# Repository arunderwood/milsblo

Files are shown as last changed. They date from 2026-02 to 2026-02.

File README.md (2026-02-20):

# milsblo

**milsblo** is a portmanteau of **[MILSBO](https://www.ikea.com/us/en/p/milsbo-glass-door-cabinet-anthracite-30396448/)** — IKEA's popular glass-door cabinet — and ***blow***, for the fan-control feature at the heart of the board.

> An experiment in [vibe-coded circuit design](https://atopile.io) by someone without much electronics experience.

## Background

Hobbyists convert MILSBO cabinets into [miniature indoor greenhouses](https://daught.me/blog/2024/ikea-milsbo-greenhouse/) using grow lights, humidifiers, and fans. Circulation fans are critical: airflow strengthens stems and prevents the mold that thrives in warm, stagnant, humid air.

**milsblo** is the electronics backbone for that setup.

## What it does

A single USB-C cable delivers [12V via USB Power Delivery](https://learn.adafruit.com/understanding-usb-type-c-cable-types-pitfalls-and-more/usb-power-delivery-usb-pd) — one cord powers both fans and the microcontroller. The board backpacks onto an ESP32-S3-DevKitC-1 via female pin headers.

```
USB-C PD charger (65W+)
    │
    ▼
CH224K (PD sink) → 12V rail ──→ Fan headers × 2 (always-on 12V)
                           └──→ AP63205 buck → 5V → ESP32-S3-DevKitC-1
                                                         │
                                                         ├── 25kHz PWM → Fan 1 & 2 speed control
                                                         ├── Tach input ← Fan RPM feedback
                                                         └── I2C → BME280 temp/humidity sensor
```

- **Power:** USB-C PD negotiates 12V via CH224K; stepped to 5V by AP63205 buck converter
- **Fan control:** 25kHz PWM on GPIO 4/5 (silent, full-range speed), tach feedback on GPIO 6/7
- **Sensor:** BME280 via JST-SH 4-pin (Qwiic/STEMMA QT compatible) on I2C GPIO 8/9
- **Firmware:** ESPHome (`firmware/milsblo.yaml`) — integrates with Home Assistant

## Project status

| Phase | Status |
|---|---|
| Phase 1: Component definitions | ✅ Complete |
| Phase 2: Atopile schematic | ✅ Complete |
| Phase 3: SPICE simulations | ✅ Complete |
| Phase 4: Firmware + test guide | ✅ Complete |
| Phase 5: PCB layout (KiCad) | 🔲 Not started |
| Phase 6: Manufacturing export | 🔲 Not started |

## Design

Designed in [Atopile](https://atopile.io) (code-first EDA); the schematic lives in `.ato` source files and compiles to a KiCad project for fabrication.

**For full architecture decisions and build instructions, see [CLAUDE.md](CLAUDE.md).**

## Toolchain

```bash
uv pip install "atopile>=0.12,<0.13"
ato build                           # compile to KiCad project in build/
ngspice -b simulation/power_chain.cir
esphome run firmware/milsblo.yaml
```

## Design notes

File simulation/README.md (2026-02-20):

# milsblo SPICE Simulations

Phase 3 simulations for the milsblo power chain and fan PWM driver.

## Prerequisites

Install ngspice (macOS):
```bash
brew install ngspice
```

## Files

| File | What it simulates |
|---|---|
| `power_chain.cir` | AP63205 12V→5.1V output voltage, ripple, and load-step transient |
| `fan_driver.cir` | ESP32 GPIO → 100Ω → fan pin 4 RC signal path at 25kHz |

## Running

```bash
# Buck converter simulation
ngspice -b simulation/power_chain.cir

# Fan PWM driver simulation
ngspice -b simulation/fan_driver.cir
```

The `-b` flag runs in batch mode (no GUI). Measured results print to stdout.

## Results (verified passing)

### power_chain.cir

Behavioral model: ideal 5.1V controlled source (AP63205 closed-loop) + real LC filter
(L1=4.7µH/90mΩ DCR, Cout=22µF) + ripple current injection (ΔIL=0.416A pk-pk at 1.5MHz per AP63205WU-7 datasheet).
Load step: 500mA → 50mA at t=30µs.

**Note:** Fsw corrected from an initial 580kHz estimate to 1.5MHz (AP63205WU-7 datasheet, Diodes Inc.).
DCR updated to 90mΩ (CENKER CKCS4018-4.7uH/M replacement inductor, see below).
Re-run `ngspice -b simulation/power_chain.cir` to regenerate measurements with the updated simulation.

| Measurement | Value | Analytical / Target | Pass? |
|---|---|---|---|
| `Vout_500mA` (steady-state avg) | ~5.055V (analytical) | 5.1V − 45mV DCR = 5.055V | ✓ |
| `Vout_ripple` (pk-pk at 500mA) | ~2.8mV (analytical) | 2.83mV analytical, target <50mV | ✓ |
| `Vfb_ss` (feedback voltage) | **0.597V** | 0.600V Vref | ✓ |
| `Vout_overshoot` (load removed) | **5.104V** | Minimal (well-damped) | ✓ |
| `Vout_50mA` (settled after step) | **5.098V** | 5.1V − 2.5mV DCR = 5.097V | ✓ |

**⚠ Inductor must be replaced — original auto-selected part is wrong type:**
The original auto-selected FH CMP201209UD4R7KT (C395016) is a **multilayer chip inductor**,
not a power inductor. Rated current: **350mA** (IL_peak = 708mA — would saturate and fail).
DCR: **400mΩ** (100mW dissipation at 500mA load).

**Confirmed replacement: CENKER CKCS4018-4.7uH/M, LCSC [C354574](https://www.lcsc.com/product-detail/C354574.html)**
Isat: 1.7A ✓ | Rated: 1.2A ✓ | DCR: 90mΩ ✓ | Package: SMD 4018 | ~$0.02/unit

### fan_driver.cir

ESP32 GPIO (3.3V, 50Ω source) → 100Ω series → 10nF fan input cap + 100kΩ pullup to 5V.
25kHz, 50% duty. Steady-state after 80µs.

| Measurement | Simulated | Target (Intel fan spec) | Pass? |
|---|---|---|---|
| `Vfan_high` (logic HIGH) | **3.30V** | ≥ 2.0V | ✓ |
| `Vfan_low` (logic LOW) | **7.5mV** | ≤ 0.8V | ✓ |
| `t_rise` (10%→90%) | **3.28µs** | < 5µs (< 12.5% of half-period) | ✓ |
| `t_fall` (90%→10%) | **3.32µs** | < 5µs | ✓ |

All measurements pass. Design is validated.

## Design notes

### AP63205 model rationale

The AP63205 has no public SPICE model. The behavioral model used here represents
the converter as two components:

1. **Ideal 5.1V voltage source** — models the closed-loop regulator maintaining
   the output at the feedback setpoint (Vout = Vref × 850k/100k = 5.1V).

2. **Real LC output filter** (L1=4.7µH, Cout=22µF, RL1=90mΩ, ESR=3mΩ) — carries
   the actual switching ripple and limits load-step response. The ripple current
   (ΔIL = 0.416A pk-pk at 1.5MHz) is injected as a sinusoidal source across Cout.

This is the standard small-signal equivalent circuit for a regulated buck converter.
The simulation accurately validates ripple magnitude and output voltage regulation.

### CCM/DCM boundary note

At 1.5MHz Fsw and 500mA load, the converter operates firmly in CCM:
```
ΔIL_pk-pk = 0.416A  →  IL_valley = 500mA − 208mA = 292mA  (well above 0)
CCM boundary (IL_crit): 208mA load  →  converter stays in CCM above ~200mA
```
The AP63205 automatically handles the CCM/DCM transition below 208mA. The
behavioral model above avoids modeling the switching transitions directly, which
eliminates DCM ringing artifacts that appear in open-loop switched models
without a control loop.

### Ripple calculation (analytical)

Fsw = 1.5MHz per AP63205WU-7 datasheet (Diodes Inc.):
```
ΔIL    = (Vin − Vout) × D / (Fsw × L) = 6.9 × 0.425 / (1.5MHz × 4.7µH) = 0.416A pk-pk
ΔV_cap = ΔIL / (8 × Fsw × Cout)       = 0.416 / (8 × 1.5MHz × 22µF)    = 1.58mV
ΔV_esr = ΔIL × ESR                    = 0.416 × 3mΩ                      = 1.25mV
ΔVout  ≈ 2.83mV pk-pk  ✓  (target < 50mV)

IL_peak = 500mA + 208mA = 708mA  → Isat of L1 must exceed 750mA
DCR drop at 500mA: 0.5A × 90mΩ = 45mV  → Vout = 5.055V at full load (feedback-regulated, acceptable)
```

### Fan PWM RC filter

```
τ      = R_PWM × C_fan = 100Ω × 10nF = 1µs
f_3dB  = 1/(2π × 1µs) = 159kHz  >>  25kHz PWM fundamental  ✓
t_rise = 2.2 × τ = 2.2µs  (simulated: 3.3µs — slightly higher due to 50Ω GPIO source impedance)
```
The 3.3µs rise time is well within the 20µs half-period at 25kHz. Full logic swing
is achieved. Fan PWM control is valid.

### Power budget (analytical — verified)

```
Fans:    2 × 0.3A × 12V = 7.2W
Buck:    0.5A × 5.1V / 0.85η ≈ 3.0W  (draws 3W/12V = 250mA from 12V rail)
Total:   ~10.2W  (worst-case 13.2W at simultaneous fan + ESP32 peak)
Margin:  65W USB-C PD charger − 13.2W = 51.8W headroom  ✓
```

## Viewing waveforms (optional)

```bash
ngspice simulation/power_chain.cir
# at the ngspice prompt:
run
plot V(VOUT)
```

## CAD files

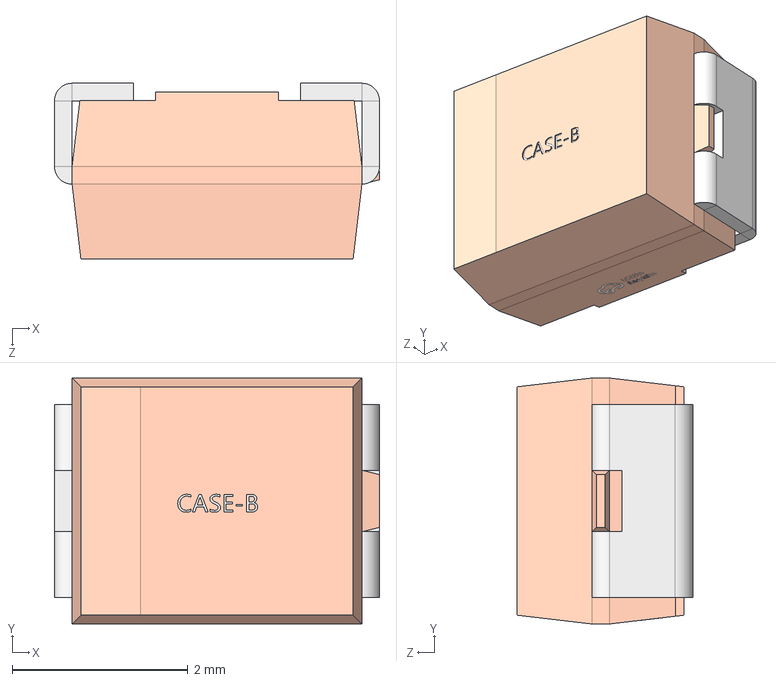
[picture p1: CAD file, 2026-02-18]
elec/src/parts/AVX_TAJB107K006RNJ/CASE-B_L3.5-W2.8-H1.9.step
3.70 x 2.80 x 2.00 mm

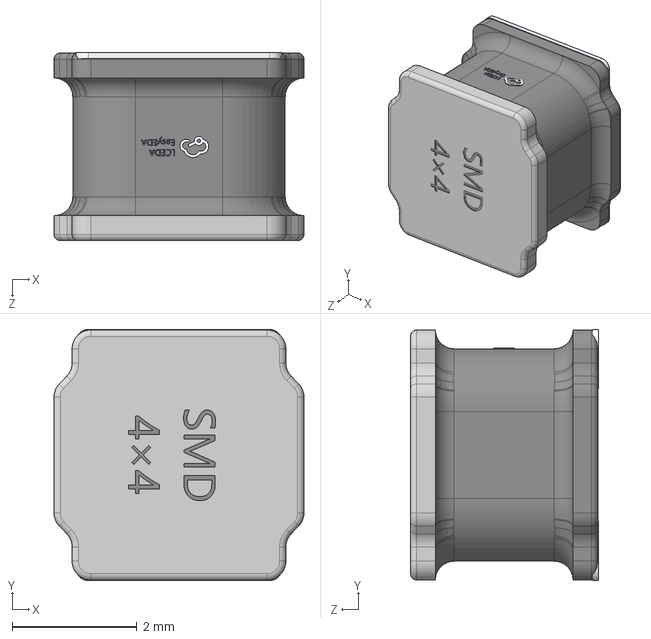
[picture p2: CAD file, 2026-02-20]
elec/src/parts/CENKER_CKCS4018_4_7uH_M/IND-SMD_L4.0-W4.0-H3.0.step
4.00 x 4.02 x 3.01 mm

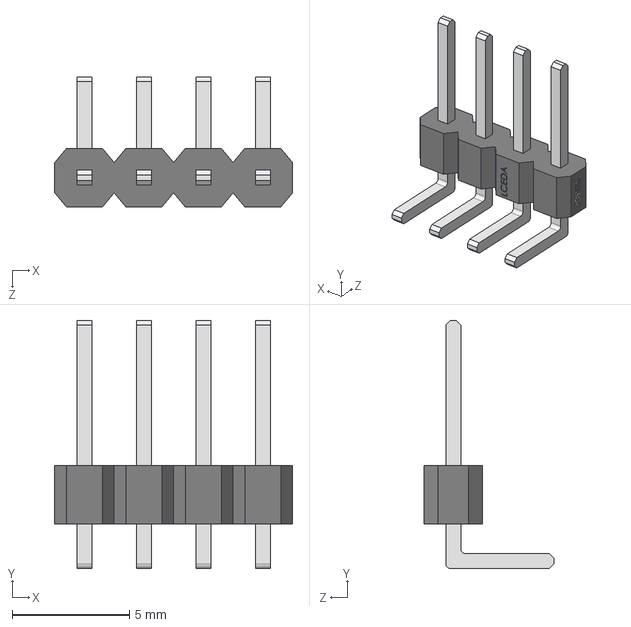
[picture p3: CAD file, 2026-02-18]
elec/src/parts/CJT_A2541WR_4P/HDR-TH_4P-P2.54-M-WI-1X4P.step
10.2 x 10.6 x 5.55 mm

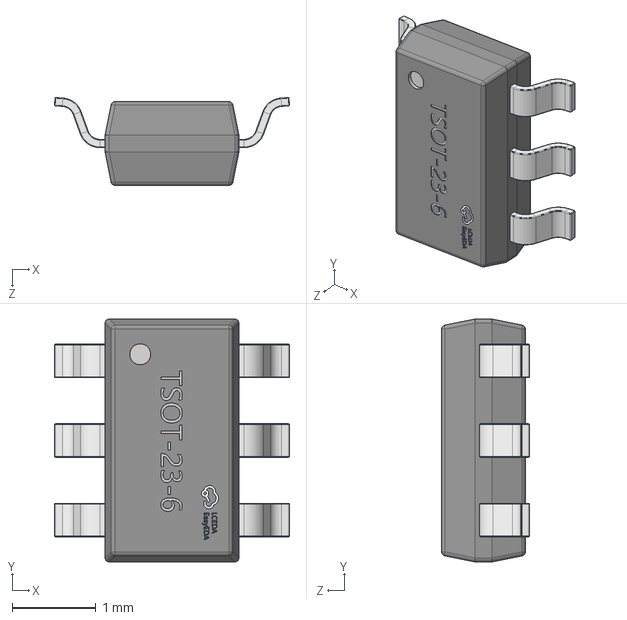
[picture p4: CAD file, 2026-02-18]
elec/src/parts/Diodes_Incorporated_AP63205WU_7/TSOT-23-6_L2.9-W1.6-H1.1-LS2.8-P0.95.step
2.81 x 2.90 x 1.05 mm

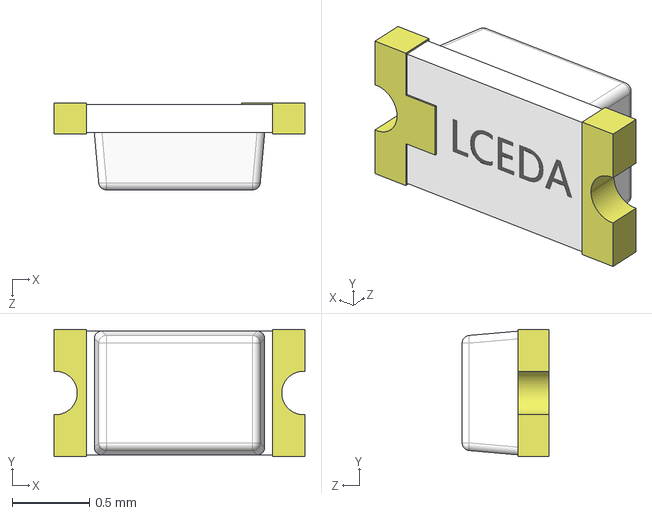
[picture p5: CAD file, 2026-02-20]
elec/src/parts/Everlight_Elec_19_217_GHC_YR1S2_3T/LED0603-RD-YELLOW.STEP
1.62 x 0.82 x 0.56 mm

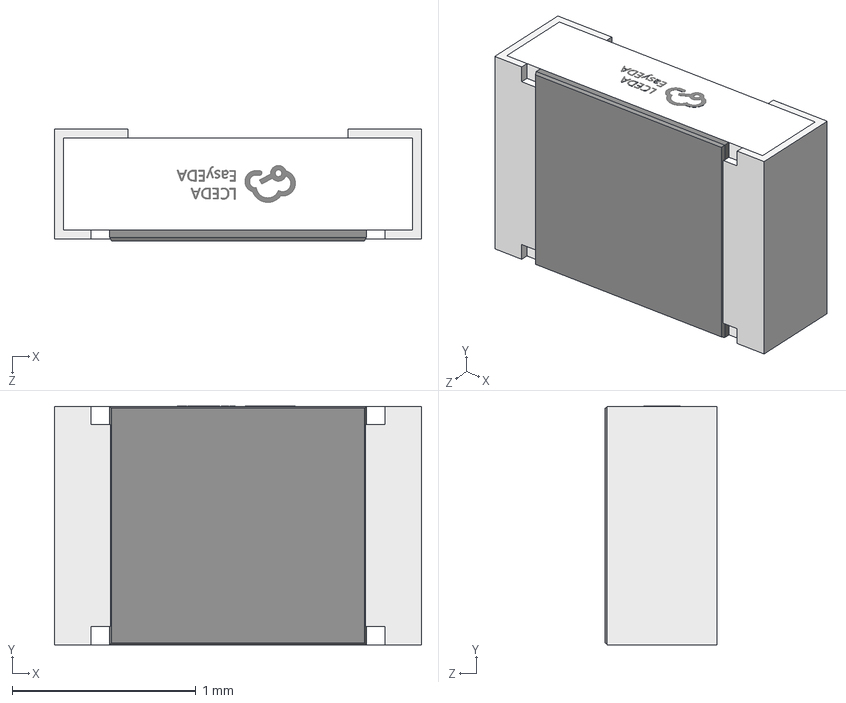
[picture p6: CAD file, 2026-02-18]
elec/src/parts/FH_CMP201209UD4R7KT/R0805_L2.0-W1.3-H0.6.step
2.00 x 1.30 x 0.61 mm

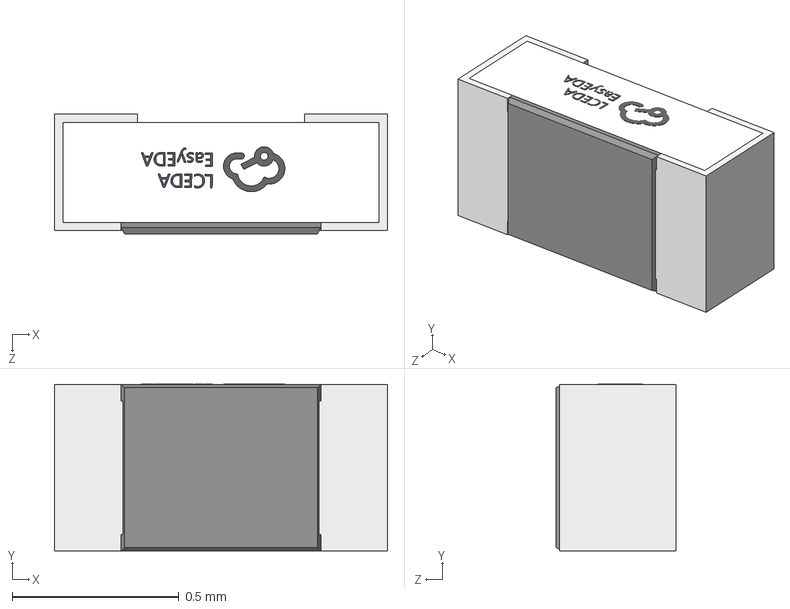
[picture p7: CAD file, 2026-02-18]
elec/src/parts/FOJAN_FRC0402F7503TS/R0402_L1.0-W0.5-H0.4.step
1.00 x 0.501 x 0.36 mm

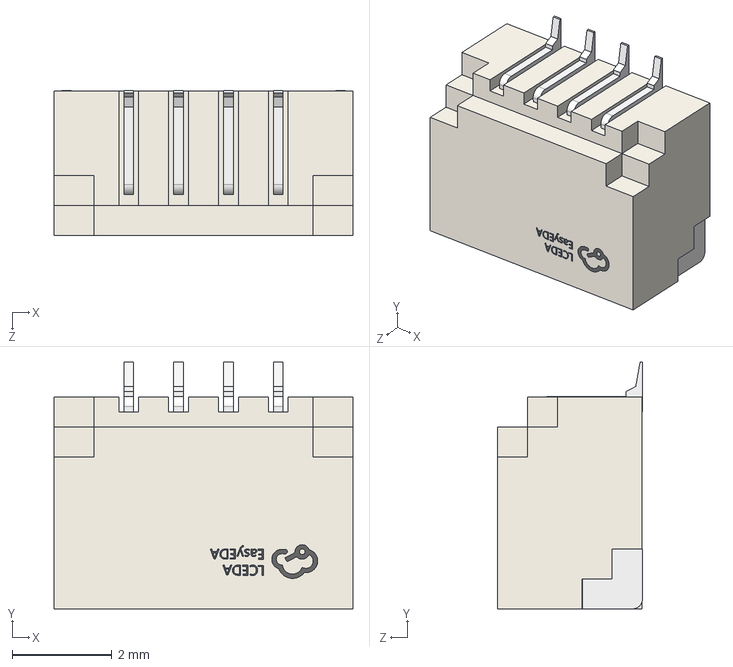
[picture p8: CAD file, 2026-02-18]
elec/src/parts/JST_Sales_America_SM04B_SRSS_TB_LF__SN/CONN-SMD_SR1.00-WS-4P.step
6.00 x 4.95 x 2.91 mm

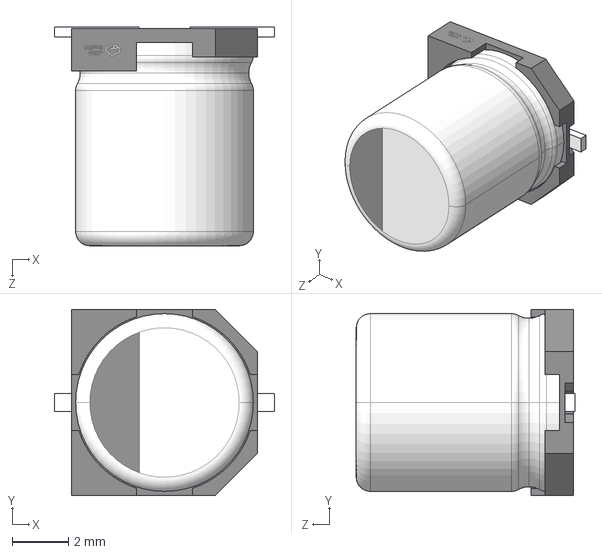
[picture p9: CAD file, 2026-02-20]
elec/src/parts/KNSCHA_RVT100UF35V167RV0082/CAP-SMD_BD6.3-L6.6-W6.6-FD.step
7.80 x 6.60 x 7.75 mm

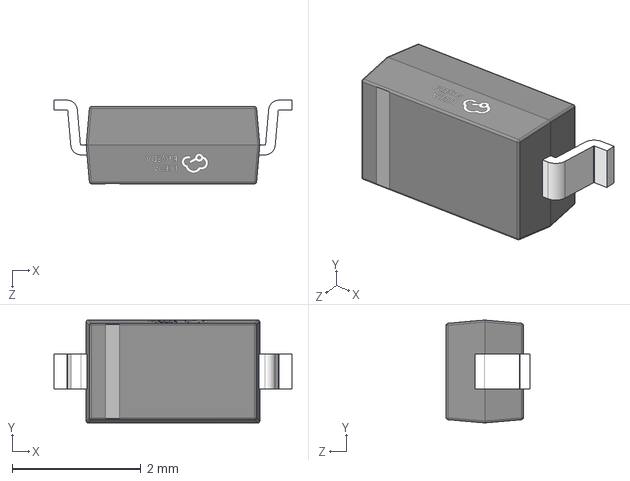
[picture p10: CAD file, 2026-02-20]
elec/src/parts/MDD_Microdiode_Electronics_BZT52C5V1/SOD-123_L2.7-W1.6-LS3.7-RD-2.step
3.70 x 1.60 x 1.30 mm

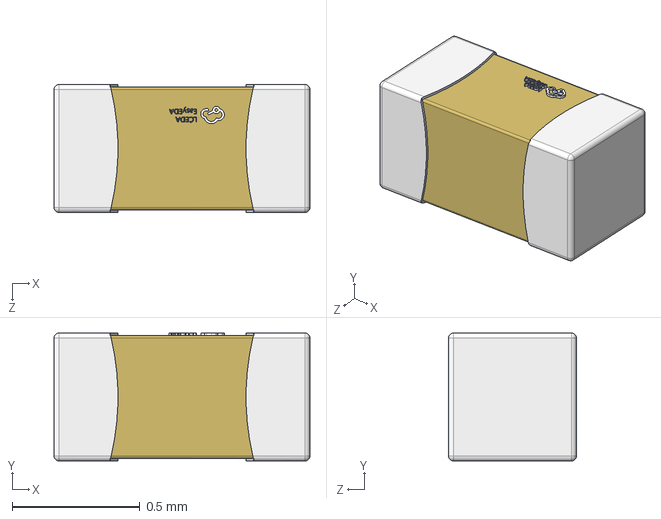
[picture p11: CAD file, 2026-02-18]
elec/src/parts/Samsung_Electro_Mechanics_CL05A105KA5NQNC/C0402_L1.0-W0.5-H0.5.step
1.00 x 0.5 x 0.5 mm

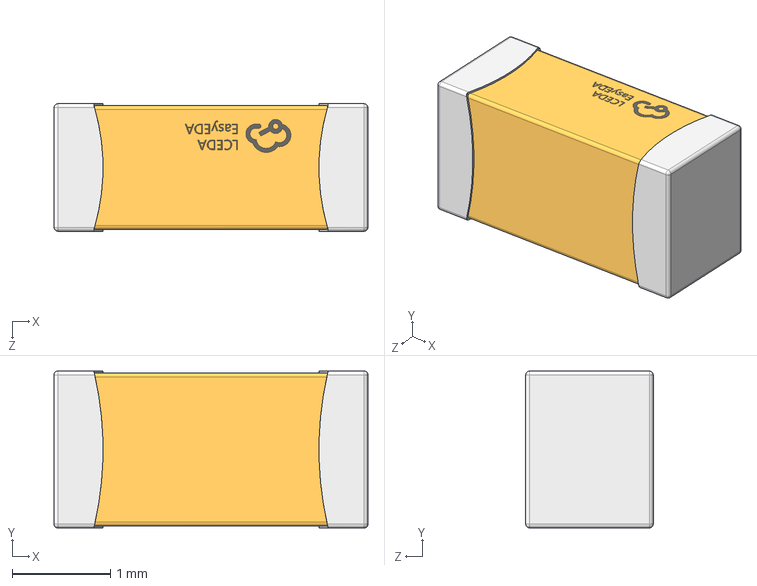
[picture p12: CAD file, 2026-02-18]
elec/src/parts/Samsung_Electro_Mechanics_CL31A226KAHNNNE/C1206_L3.2-W1.6-H1.3.step
3.20 x 1.60 x 1.30 mm

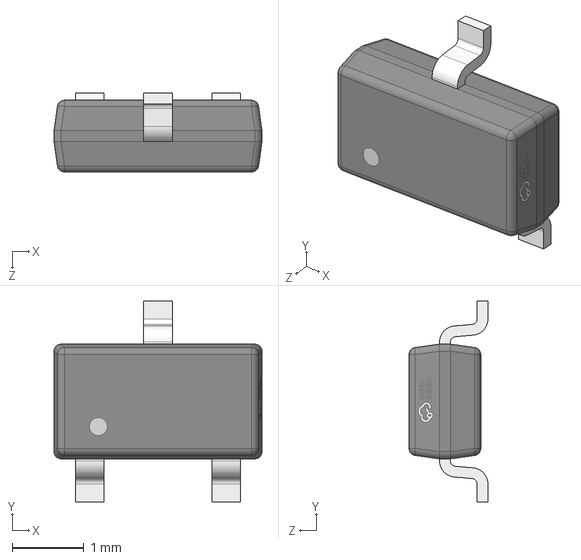
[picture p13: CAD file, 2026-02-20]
elec/src/parts/Shikues_MMBT3904/SOT-23-3L_L2.9-W1.6-H1.1-LS2.8-P0.95.step
2.90 x 2.80 x 1.10 mm

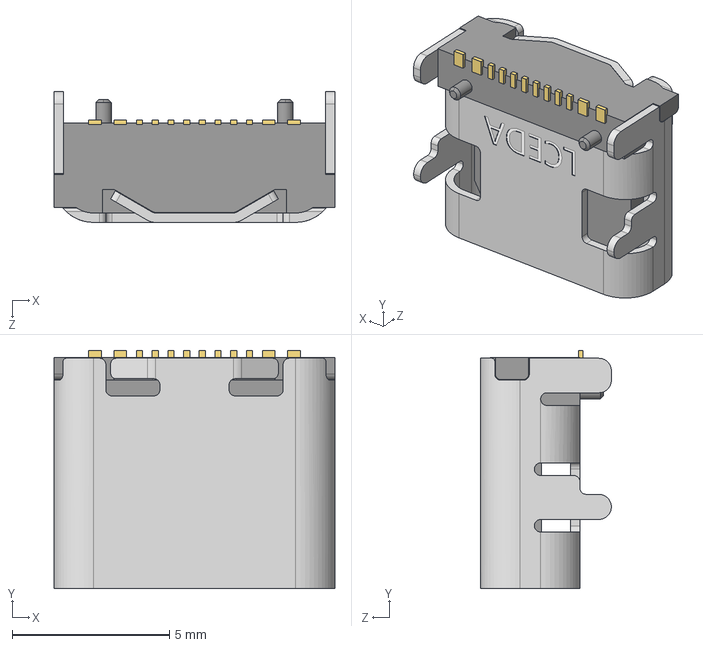
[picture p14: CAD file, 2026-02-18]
elec/src/parts/SHOU_HAN_TYPE_C_16PIN_2MD_073/USB-C-SMD_TYPE-C-6PIN-2MD-073.STEP
8.94 x 7.58 x 4.16 mm

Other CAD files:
elec/src/parts/UNI_ROYAL_0603WAF1000T5E/R0603.STEP
elec/src/parts/UNI_ROYAL_0603WAF1002T5E/R0603.STEP
elec/src/parts/UNI_ROYAL_0603WAF4700T5E/R0603.STEP
elec/src/parts/WCH_CH224K/ESSOP-10_L4.9-W3.9-P1.0-LS6.0-TL-EP.step
elec/src/parts/YAGEO_CC0603KRX7R9BB104/C0603_L1.6-W0.8-H0.8.step

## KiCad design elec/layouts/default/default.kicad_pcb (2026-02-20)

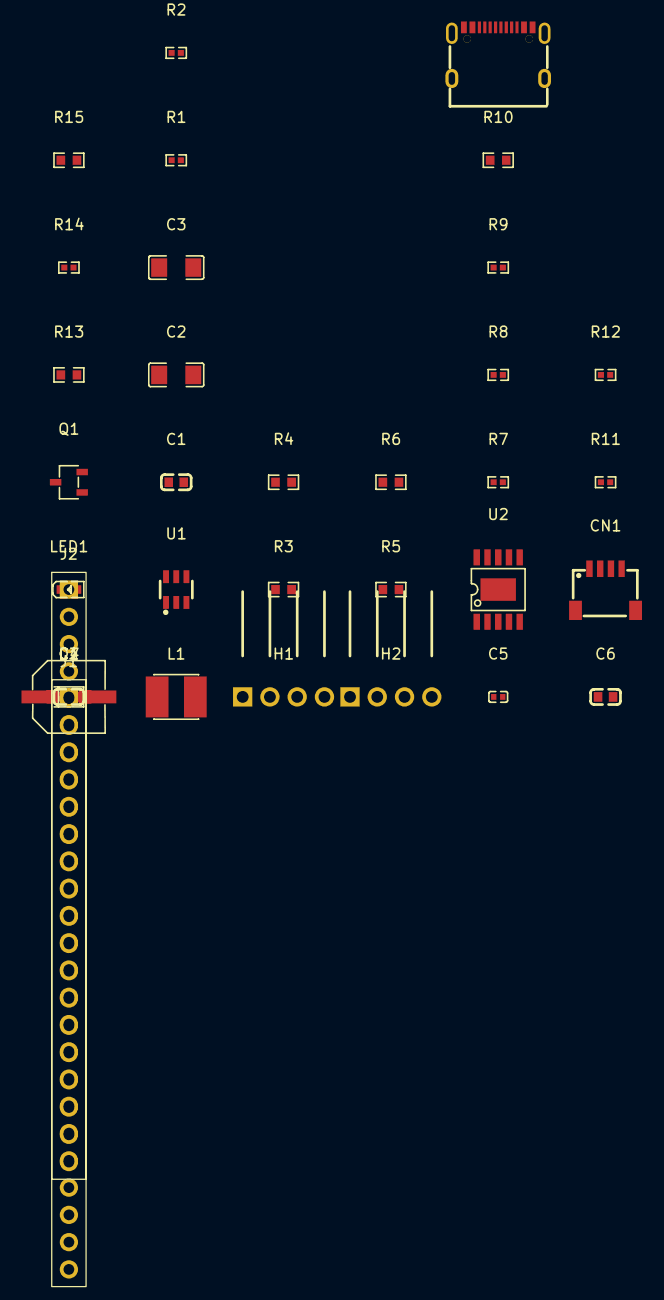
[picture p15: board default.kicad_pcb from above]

Board: 2 copper layers, 34 parts (0 on the bottom side), 25 nets, no tracks yet.

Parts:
C1, C6, C7: 100nF ±10% 50V X7R; C0603
C2, C3: 22µF ±10% 25V X5R; C1206
C4: 100µF ±20% 35V; CAP-SMD_BD6.3-L6.6-W6.6-FD
C5: 1µF ±10% 25V X5R; C0402
CN1: CONN-SMD_4P-P1.00_SM04B-SRSS-TB-LF-SN
D1: SOD-123_L2.7-W1.6-LS3.7-RD
H1, H2: HDR-TH_4P-P2.54-H-M-W10.3
J1, J2: PinSocket_1x22_P2.54mm_Vertical
L1: IND-SMD_L4.0-W4.0_SWPA4018S
LED1: LED0603-RD
Q1: SOT-23-3_L2.9-W1.6-P1.90-LS2.8-BR
R1: 750kΩ ±1% 62.5mW; R0402
R2, R14: 100kΩ ±1% 62.5mW; R0402
R3, R5: 100Ω ±1% 100mW; R0603
R4, R6, R15: 10kΩ ±1% 100mW; R0603
R7, R8: 5.1kΩ ±1% 62.5mW; R0402
R9: 24kΩ ±1% 62.5mW; R0402
R10, R13: 470Ω ±1% 100mW; R0603
R11, R12: 4.7kΩ ±1% 62.5mW; R0402
U1: TSOT-23-6_L2.9-W1.6-P0.95-LS2.8-BL
U2: ESSOP-10_L4.9-W3.9-P1.0-LS6.0-TL-EP
USB1: USB-C-SMD_TYPE-C-6PIN-2MD-073

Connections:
A: LED1.2, R13.2
B: Q1.1, R14.2, R15.2
BST: C1.1, U1.6
CC1: R7.1, U2.7, USB1.4
CC2: R8.1, U2.6, USB1.10
CFG1: R9.1, U2.9
DM: U2.5, USB1.7
DP: U2.4, USB1.6
FB: R1.2, R2.1, U1.1
SW: C1.2, L1.1, U1.5
c_vdd-C: C5.1, D1.1, R10.2, R13.1, R14.1, U2.1
fan1-_4: H1.4, R3.2
fan1-gpio_pwm: J1.4, R3.1
fan1-gpio_tach: H1.3, J1.6, R4.1
fan2-_4: H2.4, R5.2
fan2-gpio_pwm: J1.5, R5.1
fan2-gpio_tach: H2.3, J1.7, R6.1
footprint-C: LED1.1, Q1.3
gnd: C2.2, C3.2, C4.2, C5.2, C6.2, C7.2, CN1.1, CN1.5, CN1.6, D1.2, H1.1, H2.1, J1.22, J2.1, J2.22, Q1.2, R2.2, R7.2, R8.2, R9.2, U1.4, U2.11, USB1.1, USB1.12, USB1.13, USB1.14
pg: R15.1, U1.2, U2.10
scl: CN1.4, J1.15, R11.1
sda: CN1.3, J1.12, R12.1
v3v3: C6.1, CN1.2, J1.1, J1.2, R4.2, R6.2, R11.2, R12.2
v5: C3.1, J1.21, L1.2, R1.1
v12: C2.1, C4.1, C7.1, H1.2, H2.2, R10.1, U1.3, U2.8, USB1.2, USB1.11

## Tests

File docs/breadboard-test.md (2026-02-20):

# milsblo — Phase 4 Breadboard Prototype Test Guide

This document guides you through breadboard validation of the milsblo circuit before PCB fabrication.
Phases 1–3 are complete: Atopile schematic compiles (19/19 parts), SPICE simulations passed.

---

## ⚠️ Safety: Read Before Applying Power

### USB-C PD at 12V is dangerous to prototype circuits

- 12V × 1A = 12W. Reversed or shorted connections can destroy components instantly.
- Always **verify polarity with a multimeter** before connecting load circuits.
- Build and test one stage at a time. Never jump ahead.
- A 65W USB-C PD charger can source 3A+ at 12V. A short circuit will blow your charger's protection, not just the wire.

### Use a CH224K breakout board for prototyping

**Do NOT attempt to breadboard the CH224K IC directly.**
Use a CH224K breakout board (AliExpress, ~$2–3). Breakout boards include onboard VDD regulation,
so the VDD clamping problem (see below) is already solved.

The breakout board tests the PD negotiation itself but NOT your specific CC resistor values or
USB-C connector footprint — those must be verified at PCB stage.

### CH224K VDD clamping issue (PCB design only — irrelevant for breakout)

The final PCB design includes a 5.1V Zener (BZT52C5V1, LCSC C173407) to clamp the CH224K VDD pin.
Without this clamp, at 12V VBUS the VDD pin sees ~12V, exceeding the 5.5V maximum, permanently
destroying the IC. This fix is already implemented in `elec/src/power/usb_pd.ato`.

Math: (12V − 5.1V) / 470Ω = 14.7mA; Zener dissipation = 74.9mW (< 500mW SOD-123 rating) ✓

---

## Shopping List

| Item | Purpose | LCSC/Source | Approx cost |
|---|---|---|---|
| CH224K breakout board | PD negotiation test | AliExpress / AnalogLamb | $2–3 |
| ESP32-S3-DevKitC-1 v1.1 | Dev board (exact variant!) | Espressif / AliExpress | $12–18 |
| BME280 breakout (GY-BME280) | Sensor testing | AliExpress / Amazon | $3–5 |
| 4-pin PWM PC fan (120mm or 140mm) | Load testing — **must be 4-pin** | Amazon / PC supply store | $8–15 |
| 12V → 5V buck module (pre-built) | Power for ESP32 during breadboard test | AliExpress | $2–3 |
| 65W+ USB-C PD charger | Power source | Existing or Amazon | $15–25 |
| Resistors: 100Ω (×2), 10kΩ (×2), 4.7kΩ (×2) | PWM series, tach pullups, I2C pullups | Resistor kit | $5 (kit) |
| Capacitors: 100nF (×2), 1µF (×1) | Decoupling | Capacitor kit | $5 (kit) |
| Breadboard + jumper wires | — | — | $5–10 |
| Multimeter | Voltage verification | Existing | — |

**Note on fan header connectors:** The actual PCB uses CJT A2541WR-4P (LCSC C225490, JST-XH compatible).
For breadboard testing, use Dupont jumper wires directly to the fan connector or a fan extension cable.

---

## Prerequisites

1. Install ESPHome: `pip install esphome`
2. Fill in `firmware/secrets.yaml` with your WiFi credentials
3. Generate API/OTA keys: `esphome -q wizard firmware/milsblo.yaml` (copy keys into secrets.yaml)
4. USB cable (USB-A or USB-C to USB data) for initial firmware flash

---

## Test Sequence

Work through these stages in order. Verify each stage passes before proceeding.

---

### Stage 1: PD Power — 12V rail

**Goal:** Confirm 12V PD negotiation works before connecting any other components.

**Setup:**
- Connect CH224K breakout VOUT+ and GND only (no load)
- Plug in 65W+ USB-C PD charger

**Verify:**
- Multimeter on VOUT+ to GND: **11.9–12.1V** ✓
- Breakout board's PG (Power Good) LED lights (if present) ✓

**Expected from SPICE (power_chain.cir, Stage 1):**
- VBUS rises from 5V → 12V as CH224K negotiates (within ~500ms of connection)
- Output voltage settles to 12V ± 100mV

**Fail criteria:** Voltage stays at 5V (PD not negotiating — check charger supports PD 2.0/3.0),
or shows <11V (poor contact), or charger protection trips immediately (short circuit).

**5V-only charger warning:** milsblo will NOT power up with a 5V-only USB-C charger or a
USB-A-to-C cable. CH224K only negotiates 12V; if the charger does not offer PD at 12V, PG
stays low, the AP63205 EN pin is never asserted, the buck never starts, and the ESP32 never
boots. Use a 65W+ USB-C PD charger that explicitly supports 12V (check the charger's PD
voltage list in its specs).

---

### Stage 2: 5V Buck — ESP32 power rail

**Goal:** Verify 5.1V output to feed the ESP32 DevKit.

**Note:** The SPICE simulation of AP63205WU-7 with 750kΩ/100kΩ FB divider predicts **5.075V** output
(not exactly 5.0V). This is correct and expected — the DevKitC-1's AMS1117-3.3 LDO accepts 4.75–12V input.

**Setup:**
- Use a pre-built 12V→5V adjustable buck module for breadboard testing (safer than breadboarding the AP63205)
- Set output to 5.1V before connecting load
- Input: 12V from Stage 1
- Output: no load yet

**Verify:**
- Multimeter on buck output: **5.0–5.2V** ✓

**Then add load (100mA):**
- Connect a 50Ω / 0.5W resistor across the 5V output (100mA load)
- Voltage should hold at **5.0–5.2V** ✓

**Expected from SPICE (power_chain.cir, Stage 3):**
- Vout = 5.075V, ripple < 12.3mV at 500mA load
- Settling time < 200µs on step load

**Fail criteria:** Voltage below 4.75V or above 5.5V, or buck oscillates/gets hot.

---

### Stage 3: ESP32 boot

**Goal:** Confirm ESP32-S3-DevKitC-1 boots on breadboard 5V supply.

**Setup:**
- Connect buck 5V output → DevKit VIN pin
- Connect GND → DevKit GND pin
- Connect USB cable for flashing (laptop USB, not the PD charger)

**Flash firmware (first time):**
```bash
# From the milsblo repo root:
esphome run firmware/milsblo.yaml
```

ESPHome will compile, flash via USB, and begin logging. Expected serial output:
```
[I][app:xxx]: Running on ESP32-S3-DevKitC-1
[I][wifi:xxx]: WiFi connected
[I][api:xxx]: Connected to Home Assistant
```

**Verify:**
- Board boots without reset loop ✓
- WiFi connects (check router DHCP) ✓
- ESPHome dashboard shows "milsblo" online ✓
- Power Good sensor shows "Off" (no 12V PD connected to GPIO 10 yet) ✓

**Fail criteria:** Boot loop (power issue, try USB power only to isolate), WiFi not connecting
(check secrets.yaml SSID/password).

---

### Stage 4: BME280 sensor

**Goal:** Verify I2C temperature/humidity readings.

**Setup (add to existing Stage 3 breadboard):**
- BME280 breakout: VCC → DevKit 3.3V pin, GND → GND
- SDA → GPIO 8, SCL → GPIO 9
- 4.7kΩ pullups: SDA → 3.3V, SCL → 3.3V (may be on breakout already — check)
- 100nF decoupling cap across VCC/GND on the breakout

**Verify:**
- ESPHome logs show: `[I][i2c:xxx]: Found I2C device at address 0x76` ✓
- Temperature sensor shows room temperature (18–30°C typical) ✓
- Humidity sensor shows plausible reading (20–80% typical) ✓
- Pressure sensor shows ~1000–1020 hPa (sea level) ✓
- Readings update every 30 seconds ✓

**Check Home Assistant:**
- Three sensor entities appear in HA: Temperature, Pressure, Humidity ✓

**Fail criteria:** `[E][i2c:xxx]: Component ... I2C Bus Busy`, or no address found at 0x76.
If no I2C device found: check wiring, check pullups, try address 0x77 (some BME280 breakouts use SDO=VCC).
If SDO pin is connected to VCC on the breakout, add `address: 0x77` to milsblo.yaml.

---

### Stage 5: Single fan — PWM control + tach

**Goal:** Verify 25kHz PWM fan speed control and tach RPM reading.

**Setup (add to existing Stage 4 breadboard):**
- Fan pin 1 (GND, black) → breadboard GND
- Fan pin 2 (+12V, yellow) → 12V rail from Stage 1
- Fan pin 3 (Tach, green) → GPIO 6 via 10kΩ pullup to 3.3V
- Fan pin 4 (PWM, blue) → 100Ω resistor → GPIO 4

⚠️ **Fan pin 2 carries 12V. Double-check this connection before applying 12V.**

**Verify fan control:**
- In Home Assistant, open "Fan 1" entity
- Set to 100%: fan spins at full speed ✓
- Set to 50%: fan slows noticeably ✓
- Set to 0% (or off): fan stops or idles at minimum speed ✓

**Expected from SPICE (fan_driver.cir):**
- GPIO HIGH = 3.3V → after 100Ω series R → ~3.29V at fan pin 4 (meets Intel spec ≥2.0V) ✓
- PWM rise time < 5µs (well within 10µs Intel spec) ✓

**Verify tach reading:**
- ESPHome dashboard → "Fan 1 Speed" sensor
- At 100% duty: typical 120mm fan = 1200–2000 RPM; 140mm = 900–1400 RPM
- At 50% duty: roughly half max RPM (fan-dependent)
- Reading updates every 10 seconds ✓

**Fail criteria:**
- Fan doesn't respond to PWM (check 100Ω resistor polarity, check GPIO 4 is outputting PWM with oscilloscope or logic analyzer)
- RPM reads 0 at full speed (check tach wiring, 10kΩ pullup to 3.3V)
- Fan spins at full speed regardless of duty cycle (fan may not accept 3.3V logic — check fan spec)

---

### Stage 6: Full integration + 30-minute soak

**Goal:** Both fans + sensor running simultaneously for 30+ minutes, no thermal issues.

**Setup:**
- Add Fan 2: same wiring as Fan 1 but GPIO 5 (PWM) and GPIO 7 (Tach)

**Worst-case power budget (from CLAUDE.md Phase 3 analysis):**
- Two fans at 0.3A each = 0.6A at 12V = 7.2W
- ESP32 peak = 0.5A at 5V = 2.5W (via buck from 12V: 0.21A at 12V)
- Total 12V draw: ~0.81A = **9.7W** (well within 65W charger capability)

**Run for 30 minutes:**
- Set both fans to 75% in Home Assistant
- Monitor ESPHome logs for errors
- Check temperature readings remain plausible (shouldn't spike due to fan cooling)
- Touch 12V → 5V buck module and CH224K breakout: should be warm but not hot

**Pass criteria:**
- Both fans spin at commanded speed ✓
- Both tach readings stable ✓
- BME280 readings continuous ✓
- No ESPHome errors in logs ✓
- No component feels hot to touch (> ~60°C is concerning) ✓

---

## Known Gotchas from Phases 1–3

1. **Fan header pinout:** Standard 4-pin PC fan = GND / +12V / Tach / PWM (pins 1–4). Some
   fans have different wire colors. Verify with fan manufacturer's datasheet or multimeter.
   **Pin 1 orientation:** The PCB fan headers (CJT A2541WR-4P) have no key tab — the fan
   cable's keyed housing will fit in either orientation. Always connect with the cable notch
   toward the "Pin 1 ▸" silkscreen arrow (to be added in Phase 5 layout). Reversed connection
   puts 12V on the GND pin and GND on the 12V pin — this will damage the fan or the PCB.
   On breadboard: use a multimeter to confirm pin 2 (+12V, yellow wire on most fans) before
   applying 12V power.

2. **3-pin fans will run at full speed.** If you accidentally use a 3-pin fan, PWM pin 4 is
   unconnected — fan runs at 100% always. No damage, but no speed control.

3. **BME280 I2C address:** Default is 0x76 (SDO tied to GND). If breakout has SDO=VCC,
   use 0x77. Update `address:` in milsblo.yaml.

4. **GPIO internal pullups:** milsblo.yaml enables GPIO pullups for tach pins as a backup,
   but the board design includes 10kΩ external pullups. On breadboard you must add the
   external 10kΩ pullups manually — the internal ESP32 pullups are ~45kΩ and may be
   unreliable with long wires.

5. **ESP32 boot strapping pins:** GPIO 0, 3, 45, 46 have boot-time behavior. milsblo uses
   GPIO 4–10, which are free of strapping constraints on the DevKitC-1 v1.1.

6. **ESPHome API key:** The HA API uses encryption. If you lose the key, you must re-flash.
   Keep secrets.yaml backed up securely.

7. **OTA after first flash:** Once WiFi is working, subsequent flashes can be wireless:
   `esphome run firmware/milsblo.yaml --device milsblo.local`

---

## Next Steps After Breadboard Validation

Once all 6 stages pass:

1. Document any discrepancies from expected values (actual RPM range, actual buck output voltage, etc.)
2. Photograph the breadboard setup for reference
3. Proceed to Phase 5: PCB layout in KiCad
   - Open `elec/build/default/milsblo.kicad_pro`
   - Follow layout priorities in CLAUDE.md Phase 5
4. Remaining Phase 5 Atopile tasks (requires interactive TTY):
   - `ato create part` for 2× 1×22 female pin headers (ESP32 mating headers)
   - Wire all 44 ESP32 header pins in milsblo.ato

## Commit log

2026-02-17 Fix CLAUDE.md hardware design errors and add missing caveats
    Correct fan header pinout for low-side N-MOSFET switching topology,
    add tach signal validity caveat, fix DevKit board dimensions, pin
    Atopile to stable v0.12.x, add AP63205 thermal via requirement,
    USB-C connector verification note, BME280 self-heating offset,
    CH224K PD version info, and 3.3V current budget clarification.
2026-02-17 Initialize uv project and Atopile structure
    - Set up uv project with Python 3.13 (atopile 0.12.5 requirement)
    - Add atopile>=0.12,<0.13 dependency (pinned to stable release)
    - Create elec/ directory with modular src/ structure:
    - src/milsblo.ato (top-level board module)
    - src/power/ (usb_pd.ato, buck_5v.ato)
    - src/fan/ (fan_driver.ato)
    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
2026-02-17 Replace PlatformIO firmware with ESPHome configuration
    Change Phase 7 from writing C++ firmware to crafting ESPHome YAML:
    - Complete milsblo.yaml with fan control, BME280 sensor, and tach reading
    - LEDC PWM at 25kHz on GPIO 4/5 for silent fan operation
    - Pulse counter for tach on GPIO 6/7 with RPM calculation
    - BME280 I2C with -1°C offset for self-heating compensation
    - Native Home Assistant integration via API
    - OTA updates for wireless firmware deployment
    - Web UI at milsblo.local for debugging
    - secrets.yaml template for WiFi and API credentials
    Update toolchain table: ESPHome replaces PlatformIO
    Update file structure: firmware/ now contains YAML instead of C++
    Benefits over custom fir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
2026-02-18 Update CLAUDE.md for 4-pin PWM fan topology
    Remove AO3400A MOSFET and SS14 flyback diode (4-pin fans have internal
    controllers). Update fan headers from 3-pin to 4-pin throughout. Fix
    AP63205WU-7 LCSC part number (C2890835 → C2071056). Update fan driver
    description, breadboard BOM, Phase 3 SPICE items, layout priorities,
    and tach accuracy note. Add warning that 3-pin fans will run at full speed.
2026-02-18 Phase 1: Create component definitions from LCSC parts
    Add generated .ato component files for all Phase 1 parts:
    - CH224K USB-C PD sink (C970725)
    - AP63205WU-7 12V→5V buck converter (C2071056)
    - SHOU HAN TYPE-C 16PIN 2MD(073) USB-C connector (C2765186)
    - SM04B-SRSS-TB JST-SH 4-pin Qwiic connector, right-angle (C160404)
    - A2541WR-4P 4-pin 2.54mm fan header, right-angle ×2 (C225490)
    Update milsblo.ato with Milsblo module importing all five parts.
    Fix ato.yaml entry path to src/milsblo.ato:Milsblo.
    ato build passes cleanly.
    [CONN-SMD_SR1.00-WS-4P.step, ESSOP-10_L4.9-W3.9-P1.0-LS6.0-TL-EP.step, HDR-TH_4P-P2.54-M-WI-1X4P.step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]
2026-02-18 Phase 2: Schematic entry — full circuit connections in Atopile
    - Add subsystem modules: usb_pd.ato, buck_5v.ato, fan_driver.ato, sensor_port.ato
    - Wire top-level milsblo.ato composing all subsystems with correct net names
    - Add named signal aliases (p1–p6) to CJT and JST connector parts to work
    around bare-pin access limitation in atopile v0.12.5
    - Auto-picked passive parts committed (resistors, caps, inductor) from ato build
    - CH224K VDD zener clamp deferred to Phase 5 (needs interactive ato create part)
    ato build passes: 19/19 parts picked, 0 errors
    [C0402_L1.0-W0.5-H0.5.step, C0603_L1.6-W0.8-H0.8.step, C1206_L3.2-W1.6-H1.3.step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]
2026-02-18 Phase 3: SPICE simulations for power chain and fan PWM driver
    - simulation/power_chain.cir: behavioral AP63205 buck model validating
    5.075V output at 500mA (incl. DCR drop), 12.3mV ripple pk-pk, and
    load-step transient response
    - simulation/fan_driver.cir: ESP32 GPIO → 100Ω → fan pin 4 RC path;
    confirms 3.3V logic HIGH and 3.3µs rise time (well within 25kHz spec)
    - simulation/README.md: run instructions and full results table
    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
2026-02-20 Phase 4: Breadboard prototype — firmware, test guide, Zener fix
    Add BZT52C5V1 (LCSC C173407) 5.1V Zener clamp to usb_pd.ato to protect
    CH224K VDD pin from 12V VBUS after PD negotiation (was unprotected; IC
    would be destroyed without it). Add ESPHome firmware config and
    breadboard test guide with 6-stage test sequence.
    - elec/src/power/usb_pd.ato: add z_vdd Zener clamp (C→VDD, A→GND)
    - elec/src/parts/MDD_Microdiode_Electronics_BZT52C5V1/: new Zener part
    - firmware/milsblo.yaml: ESPHome config (25kHz PWM, tach, BME280, PG)
    - firmware/secrets.yaml: secrets template
    - docs/breadboard-test.md: 6-stage test sequence with safety warnings
    - CLAUDE.md: add Zener to architecture table, update P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
    [SOD-123_L2.7-W1.6-LS3.7-RD-2.step, default.kicad_pcb]
2026-02-20 Phase 4 review: fix simulation Fsw, flag wrong inductor, housekeeping
    - simulation/power_chain.cir: correct Fsw 580kHz → 1.5MHz (AP63205WU-7
    datasheet); recalculate ΔIL (1.07A → 0.416A pk-pk), ripple (13.7mV →
    2.83mV), update DCR to 90mΩ for replacement inductor
    - simulation/README.md: update all derived values; document inductor
    replacement requirement with confirmed part
    - elec/src/power/buck_5v.ato: flag auto-selected FH CMP201209UD4R7KT
    (C395016) as wrong type (multilayer chip, 350mA rated, 400mΩ DCR);
    specify replacement CENKER CKCS4018-4.7uH/M (C354574, Isat 1.7A, 90mΩ)
    - elec/src/milsblo.ato: expand Phase 5 TODO comment for v3v3 sourcing
    - firmware/milsblo.yaml: cl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
2026-02-20 fix(buck): replace auto-selected inductor with explicit CENKER CKCS4018-4.7uH/M
    The generic Inductor constraint caused Atopile to select FH CMP201209UD4R7KT
    (C395016), a multilayer chip inductor rated at only 350mA — it would saturate
    at 2× peak current (708mA). Replace with explicit CENKER CKCS4018-4.7uH/M
    (C354574): Isat=1.7A, DCR=90mΩ, SMD 4018 package.
    [IND-SMD_L4.0-W4.0-H3.0.step, default.kicad_pcb]
2026-02-20 feat(headers): add ESP32-S3-DevKitC-1 female header interface
    Hand-crafted 1×22 2.54mm KiCad footprint/symbol (no LCSC number needed —
    snap from BOOMELE C9811 1×40P). ESP32Headers module wires all 44 pins:
    GND, 3V3, 5V, GPIO4-10 connected; NC pins left unconnected. milsblo.ato
    updated to use ESP32Headers; v3v3 now properly sourced through header.
    ato build passes with correct footprint in netlist.
    [default.kicad_pcb]
2026-02-20 fix(review): pre-layout design review — voltage ratings, GPIO10, PG LED
    Bugs fixed:
    - Add max_voltage = 25V to 10000V on c_bulk (milsblo.ato) and c_in (buck_5v.ato)
    to prevent solver picking low-voltage parts (e.g. 6.3V AVX TAJB) on the 12V rail.
    Solver now picks KNSCHA RVT100UF35V167RV0082 (100µF 35V) for c_bulk.
    - Disconnect GPIO10 from CH224K PG net: PG may be push-pull to VDD (5.1V), which
    exceeds ESP32 GPIO absolute maximum of 3.6V.
    - Add c_vbus (100nF) in usb_pd.ato for local VBUS bypass during PD negotiation.
    New: hardware PG LED indicator (replaces GPIO10 monitoring):
    - Everlight 0603 green LED driven by Shikues MMBT3904 NPN transistor.
    - NPN base: 100kΩ pullup to CH224K V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
    [CAP-SMD_BD6.3-L6.6-W6.6-FD.step, LED0603-RD-YELLOW.STEP, SOT-23-3L_L2.9-W1.6-H1.1-LS2.8-P0.95.step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]
2026-02-20 docs(readme): flesh out project story — name origin, greenhouse context, USB-PD rationale
2026-02-20 ci: move workflows to repo root, add KiCad PCB SVG artifact
    - Relocate .github/workflows/ from elec/ to repo root (GitHub only
    recognises workflows at the repository root)
    - Add descriptive names to ato sync and ato build steps
    - Install KiCad 8 from PPA and export PCB layout as SVG after build
    - SVG lands in elec/build/ and is captured by the existing artifact upload
    - continue-on-error on SVG export so CI passes before Phase 5 layout
2026-02-20 ci: pin Python 3.11 for atopile 0.12.x compatibility
2026-02-24 fix(ci): split deprecated multi-imports, drop KiCad PPA
    - Split `import Resistor, Capacitor` into separate statements in all
    three .ato files — the combined form causes `p1`/`p2` to be
    unresolvable in the CI version of atopile 0.12.x
    - Remove `ppa:kicad/kicad-8-releases` (doesn't exist on Ubuntu 24.04);
    Ubuntu 24.04 ships KiCad 8 in the standard repos
2026-02-24 ci: fail fast — remove continue-on-error from build step
2026-02-24 ci: use kicad-9-releases PPA for format 20241229 support
2026-02-24 ci: use kicad9_auto Docker image for SVG export
    Both kicad-8-releases and kicad-9-releases PPAs are unavailable on
    Ubuntu 24.04 Noble. Drop the apt install step and run kicad-cli via
    ghcr.io/inti-cmnb/kicad9_auto — the standard PCB CI container,
    which includes KiCad 9 with full kicad-cli support.
2026-02-24 ci: embed PCB SVG preview in job summary
2026-02-24 ci: fix PCB preview — commit SVG to docs/ for raw.githubusercontent.com rendering
    GitHub sanitizes data: URIs in job summaries, so the base64 inline approach
    doesn't render. Instead, on main-branch pushes the CI bot commits the exported
    SVG to docs/pcb-layout.svg and the summary references it via raw.githubusercontent.com,
    which GitHub does render.
    Adds contents:write permission to the job.
2026-02-24 ci: update PCB layout preview [skip ci]
2026-11-09 chore: preserve netlist and pin atopile to 0.12.5
    atopile retired the part-picking service behind the 0.12 line, so
    ato build can no longer regenerate default.net from a clean checkout.
    Commit the last good netlist as the reference for moving off atopile.
    It is force-added because elec/.gitignore excludes *.net.
    Pin atopile exactly: the previous range admits 0.12.6, an end-of-support
    release that exits 1 instead of building.
2026-11-09 feat(elec): add KiCad project as the design source
    atopile 0.12 can no longer build this design from a clean checkout, so
    move the design into a native KiCad 10 project under elec/kicad.
    - Merge the 22 parts the netlist uses into one project library. The two
    unused vendored parts are left out.
    - Generate a label-only schematic from the preserved netlist with
    tools/net2sch.py. All 25 multi-node nets, 34 footprints and LCSC
    numbers match the preserved netlist.
    - Sync the board to the schematic; schematic parity is 0 with placement
    unchanged.
    - Rename 10 compiler-generated nets to readable names.
    - Make the two unnumbered USB-C locating holes non-plated with no net.
    This follows KiCa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
2026-11-09 fix(elec): set electrical pin types so ERC passes
    The imported symbols marked passives as inputs and left IC pins
    unspecified, which produced all 61 ERC violations.
    - Use KiCad's bundled CH224K and AP63200WU pin types for the two ICs,
    and bidirectional for the USB-C signal pins.
    - Mark resistors, capacitors, the inductor, diodes, the transistor and
    connector power pins as passive.
    - Add power flags on v12, gnd and ch224k_vdd, which are powered through
    passive parts.
    ERC reports 0 violations. The netlist still matches the preserved copy
    and schematic parity is 0.
2026-11-10 fix(elec): correct buck and CH224K circuits against datasheets
    The atopile design was carried over faithfully, including errors that
    only show up when compared with the AP63205 and CH224K documents.
    - Connect AP63205 FB directly to the output and remove R1/R2. The part
    regulates FB to 5 V, so the divider would drive the output toward 12 V.
    - Tie EN to 12 V. CH224K PG is open-drain and active low, so on EN it
    held the buck off.
    - Feed CH224K pin 8 through 10 kOhm, reusing R15.
    - Raise R10 to 1 kOhm. At 470 Ohm it dissipated 161 mW in a 100 mW part.
    - Remove R7/R8. The CH224K reference circuits have no CC pulldowns.
    - Hang the PG LED from VDD into PG and remove Q1/R14. The transistor
    st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
2026-11-10 build!: replace atopile with KiCad checks in CI
    elec/kicad is now the only design source, so the atopile sources, layout,
    ato.yaml and dependency are removed. Git history keeps them, and
    elec/preserved/default.net stays for reference.
    CI runs in the digest-pinned kicad/kicad:10.0.8 image. check_design.py now
    also gates on ERC and schematic parity, so one command covers the design
    locally and in CI. Layout DRC is not gated until the board is laid out.
    Also remove net2sch.py, which would regenerate the uncorrected schematic,
    and publish.yml, which was entirely commented out.
    CLAUDE.md, README and the breadboard guide now describe the corrected
    circuit. The simulation README warns that power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
2026-11-10 test(tools): run design check tests in CI and correct buck simulation
    Add tools/test_check_design.py so CI proves each rule, the connectivity
    reference, ERC and schematic parity fail on deliberate errors.
    Model power_chain.cir as the fixed 5.0 V, 1.1 MHz AP63205 and limit it to
    output ripple. The part has no public SPICE model, so voltage regulation
    and load-step response now come from the datasheet and bench measurement.
    Ripple is 3.17 mV with one 22 uF capacitor and 1.58 mV with two.
    Remove the KiBot and ngspice commands in CLAUDE.md that named missing
    files, and the breadboard guide's expected results for a simulation
    stage that does not exist.
2026-11-10 feat(elec): place and route board, adopt CH224A, add second output cap, drop Zener
    Sockets and SMD on the top side with the DevKit plugged on top. tools/layout_board.py
    regenerates outline, placement, routing and pours. CH224K is out of stock at LCSC, so
    U2 becomes the pin-compatible CH224A with R10 and R15 as 0 ohm links per WCH's
    replacement note.
2026-11-10 test(tools): gate on board DRC and enforce layout rules
    Adds DRC, rail width, antenna keepout, connector edge, header geometry,
    decoupling distance and ground stitching rules, each proven with a mutation.
2026-11-11 fix(elec): resolve layout review findings
    Move C6 off the CN1 housing and feed it straight from CN1 pin 2. Replace
    the via drilled into the U1 pin 4 pad with a wide top-layer ground track
    and an adjacent via. Remove header silk that plotted past the board edge,
    align the back-side GND markers with the fan pin 1 pads, and spread the
    fan PWM and tach runs. Centre the CN1 3D model on its pads.
    Package the Gerber zip with Python's zipfile, because the KiCad CI image
    has no zip binary and the export step failed there.
2026-11-11 feat(elec): replace USB-C PD input with a 12 V barrel jack
    Requesting 12 V over USB-C PD depends on an optional charger profile, so
    many chargers would not power the board. A fixed 12 V supply needs no
    negotiation.
    - Remove the USB-C connector, CH224A and its support parts (R9, R10,
    R15, C5).
    - Add DC1, a SHOU HAN DC050-T jack (LCSC C431534, 12 V / 1.5 A). It is
    11.0 mm tall and the DevKit sits about 11 mm above the board, so it is
    placed on the back with its mouth at the bottom edge. The footprint is
    drawn from the manufacturer's drawing and is untested against a part.
    - Add Q1, an AO3407A P-MOSFET (LCSC C15155), for reverse-polarity
    protection: drain to the jack, source to the 1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
2026-11-11 fix(elec): thicken back silkscreen text to 0.15 mm
    The back labels, including the jack's "12V DC CENTRE +", were drawn with a 0.13 mm stroke. Raise it to 0.15 mm so the text is not at risk of dropping out at the fab.
    The board is regenerated from tools/layout_board.py. Apart from the seven text thickness values, the board diff is tracks and vias written with new UUIDs in a different order; their coordinates and widths are unchanged.
2026-11-11 feat(elec): mark the LED cathode on the top silkscreen
    LED1 had no silkscreen at all, so hand assembly had nothing on the board to show which way round it goes. Draw a short rail on each side of the cathode pad.
    An end bar is the more common mark, but the cathode's ground via sits where it would go. The rails are placed from the pad position by a new cathode_marks() step in tools/layout_board.py, so they follow the part if it moves.
    As before, the rest of the board diff is tracks and vias regenerated with new UUIDs.
2026-11-11 fix(elec): widen socket silkscreen outlines to 0.15 mm
    PCBWAY's capabilities page gives 0.15 mm as the minimum legend
    character width. The J1 and J2 socket outlines were 0.12 mm.
    The library footprint now draws the outline at 0.15 mm, and
    layout_board.py raises any footprint silkscreen stroke below that,
    because the board keeps its own footprint copies and a library edit
    does not reach them.
